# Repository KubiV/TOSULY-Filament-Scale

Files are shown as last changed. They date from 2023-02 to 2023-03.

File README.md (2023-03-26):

# TOSULY ALFA (V0.1)
## _DIY Filament scale integrated into filament holder_

Do It Yourself Filament Spool Scale which is integrated into the filament holder so you can easily monitor your remaining filament. By default it is not using batteries so you can hook it up straight to the printer/power suply. Optionaly you can add battery by soldering extension wires to prepared pads and than attach battery. 

## Features

- Open-source
- Custom PCB
- OLED 0.96 inch display
- Buttons (one under the display so it clicks when you push the display)
- By double-clicking button subtract spool dry mass
- Powered by Arduino Nano
- Compatible with stock Ender 3 spool holder, Prusa Original frame

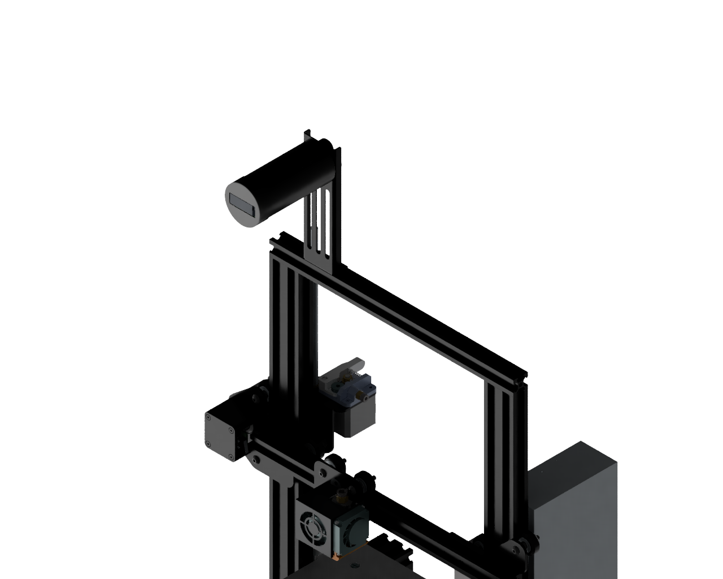
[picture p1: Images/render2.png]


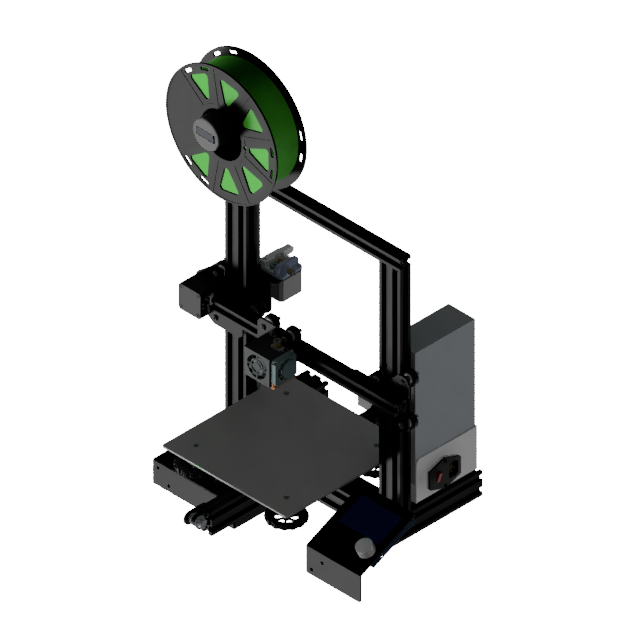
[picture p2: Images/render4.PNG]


## Needed

- 4x M3 screws (15mm for mounting PCBs)
- 2x M3 nuts (rectangle PCB mounting)
- 4x M4 screws (approx. 10 mm, and 2 with flat head)
- Custom PCB
- 7x1 horizontal pin header 2.54 mm pitch
- Arduino Nano
- USB cable (according on Arduino Nano variant)
- A DC-DC step-down converter and USB port for connecting the USB cable
- Load Cell 5 kg
- HX711 AD Module Weight Sensor
- 0.96 Inch OLED Module I2C
- 3x buttons 6 mm
- 3 resistor axial
- 3D printed parts (Upper, Body, Nut, Cover)

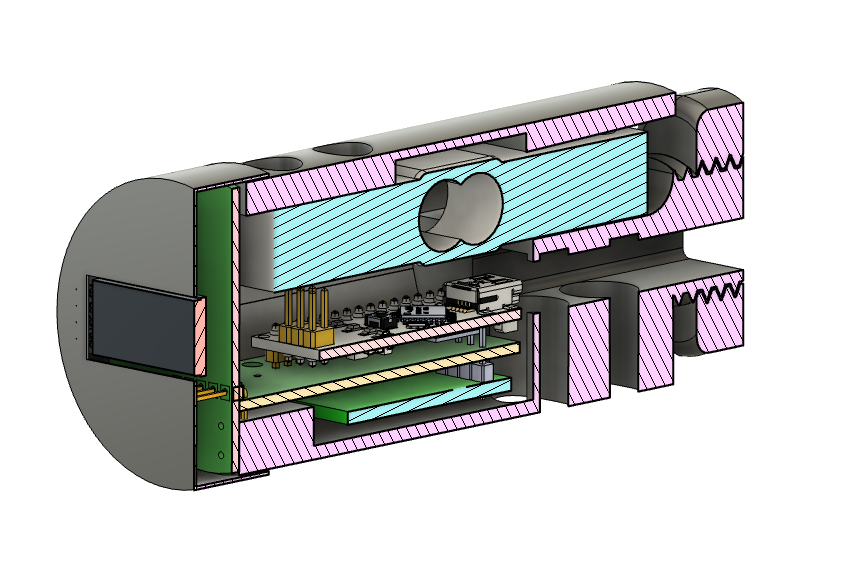
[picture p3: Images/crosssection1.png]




## Load cell

Compatible with both load cell designs - 12.7 x 12.7 x 75mm (type 1) or 12.7 x 12.7 x 80mm (type 2), holes for M4 bolts and two holes for M5 holes (type 2).

## 3D Printable parts

Mounting screw has 24 mm i diameter with according thread.

V02 design inspired by https://youtu.be/WO-hR7okl3k

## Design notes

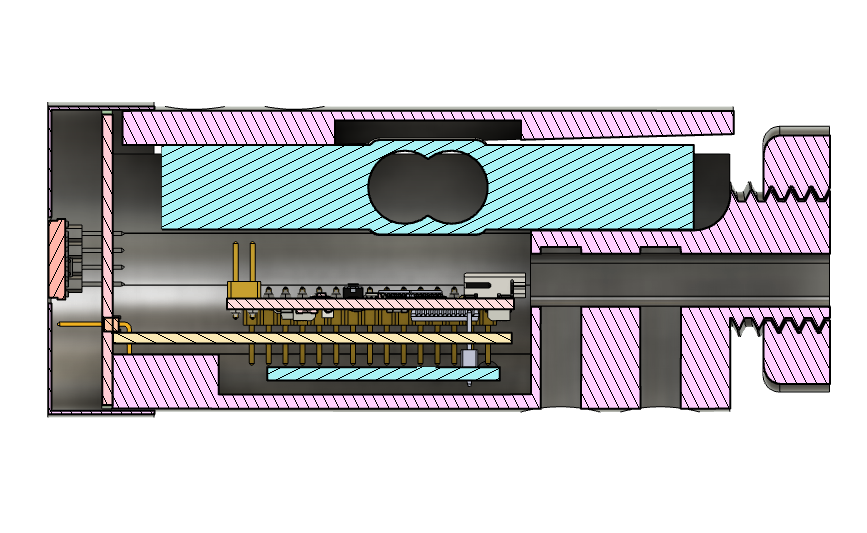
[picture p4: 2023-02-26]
Images/crosssection2.png

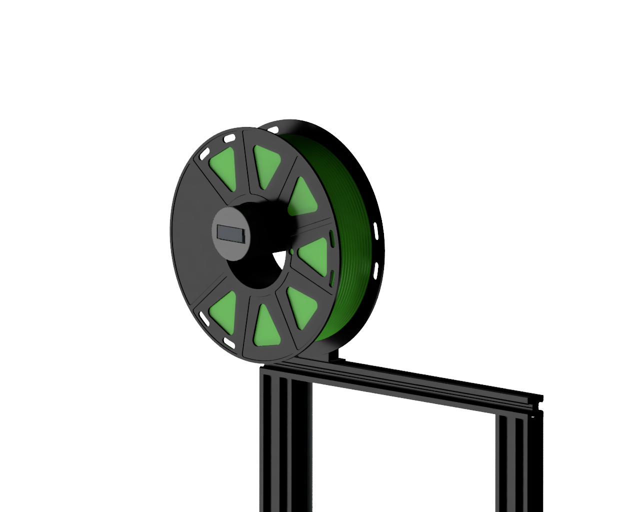
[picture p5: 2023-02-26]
Images/render3.PNG

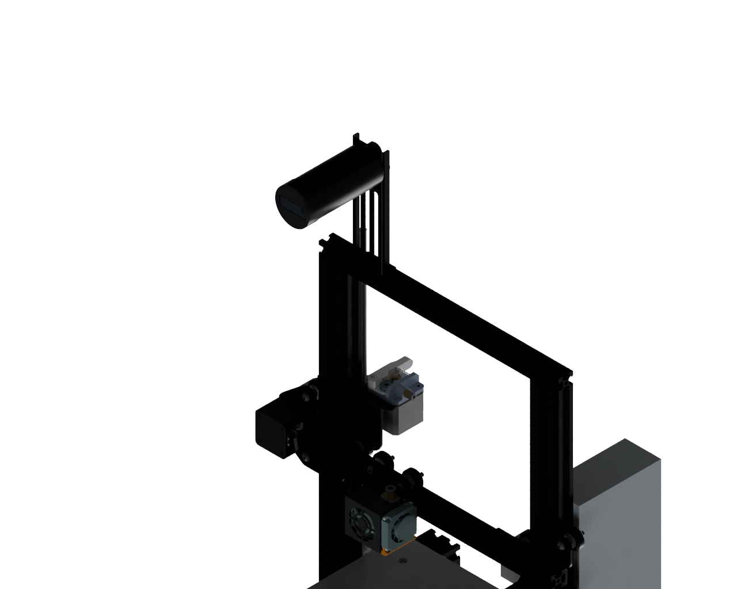
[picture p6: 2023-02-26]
Images/render1.png

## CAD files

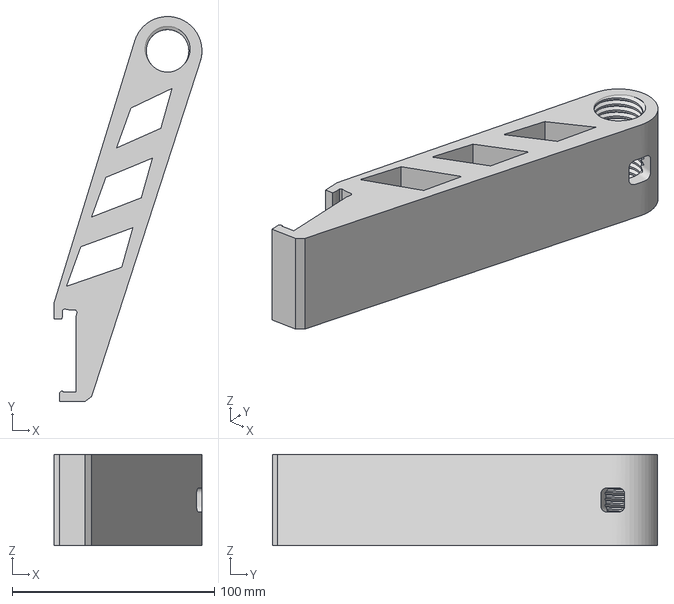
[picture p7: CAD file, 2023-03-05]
Hardware/CAD/OriginalPrusaAdaptor.3mf
73.1 x 190.3 x 45.0 mm

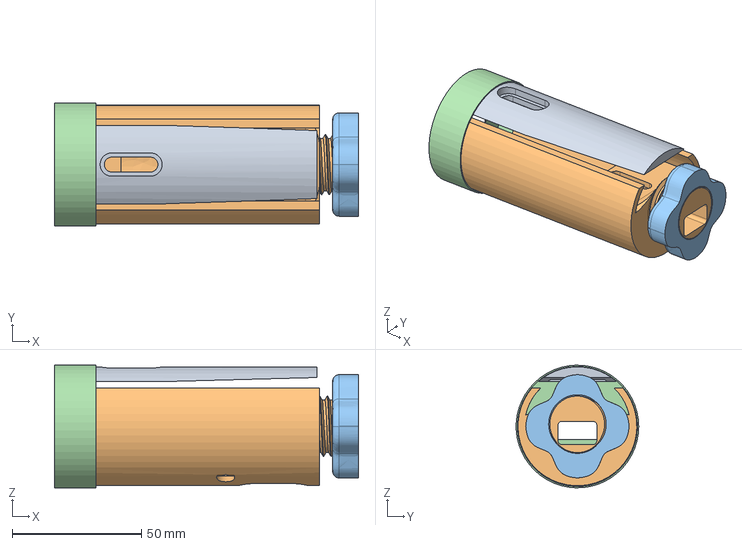
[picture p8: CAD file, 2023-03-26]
Hardware/CAD/V02/FilamentSpoolScale.step
117.7 x 47.5 x 47.5 mm

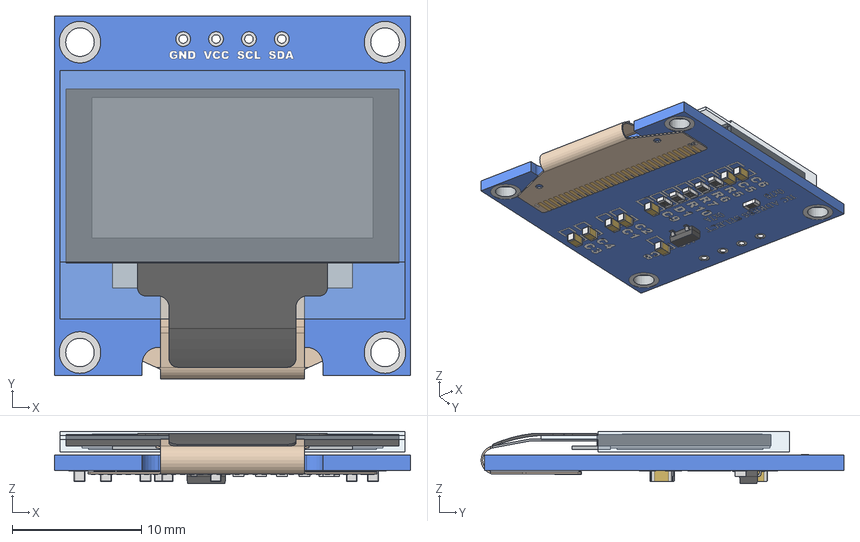
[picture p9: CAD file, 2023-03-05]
Resources/3D/0.96 OLED Module - i2C.stp
27.5 x 28.0 x 4.03 mm
0.96 OLED - Board - i2c
0.96 OLED - Glass
0.96 OLED - Flat Reverse
0603 Resistor x 6
SOT-23
0603 Capacitor x 8

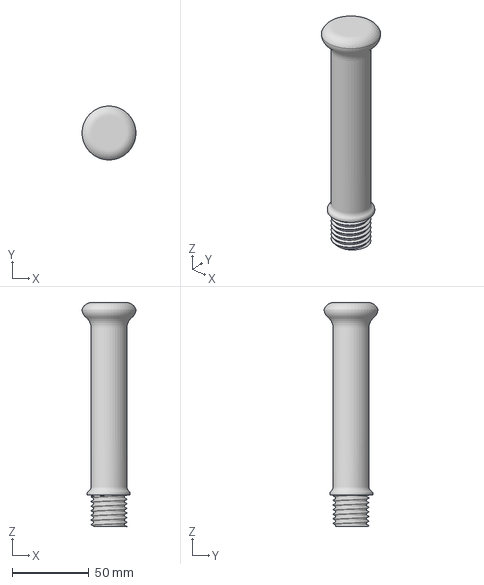
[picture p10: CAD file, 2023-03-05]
Hardware/CAD/NormalSpoolHolder.3mf
35.0 x 34.9 x 145.5 mm

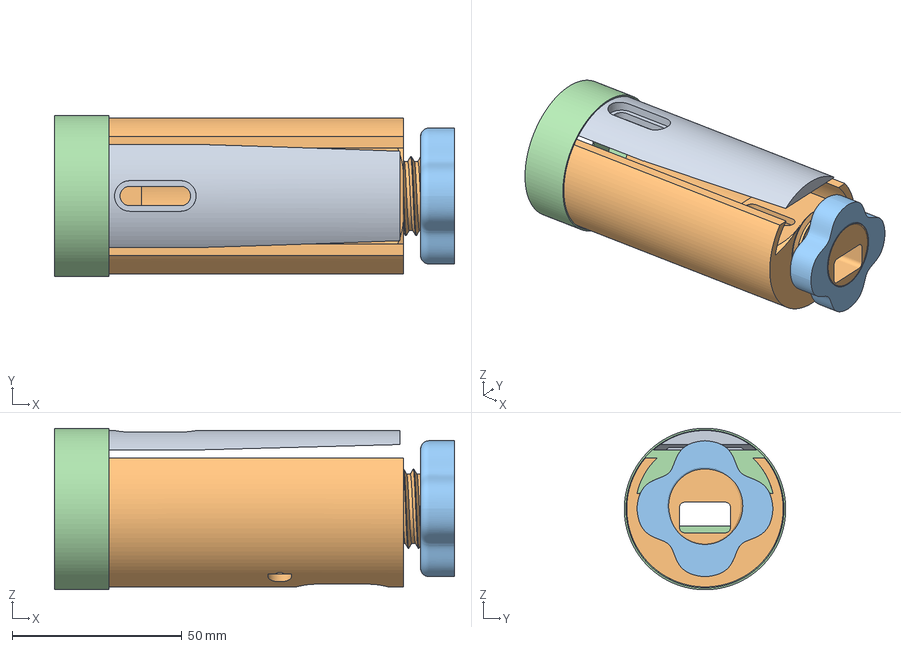
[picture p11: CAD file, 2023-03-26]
Hardware/CAD/V02/3Dprint_FilamentSpoolScaleV02.3mf
117.7 x 47.5 x 47.5 mm

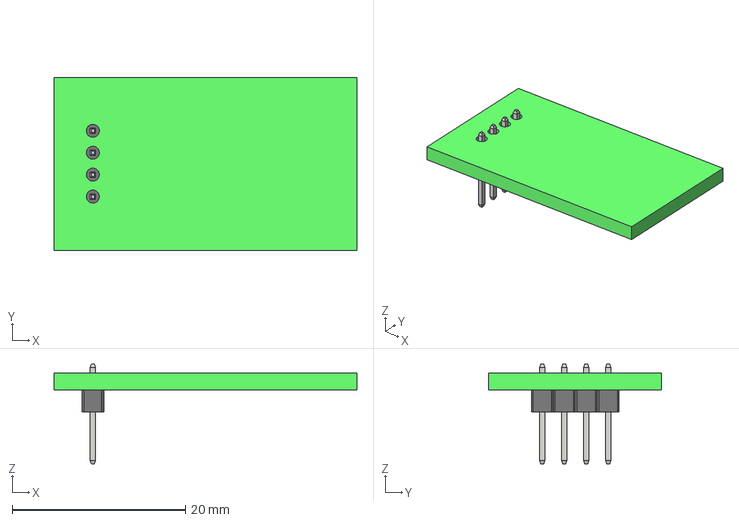
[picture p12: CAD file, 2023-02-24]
Resources/3D/XH711.step
35.0 x 20.0 x 11.5 mm
1x1_Pin_Header_2.54mm x 4

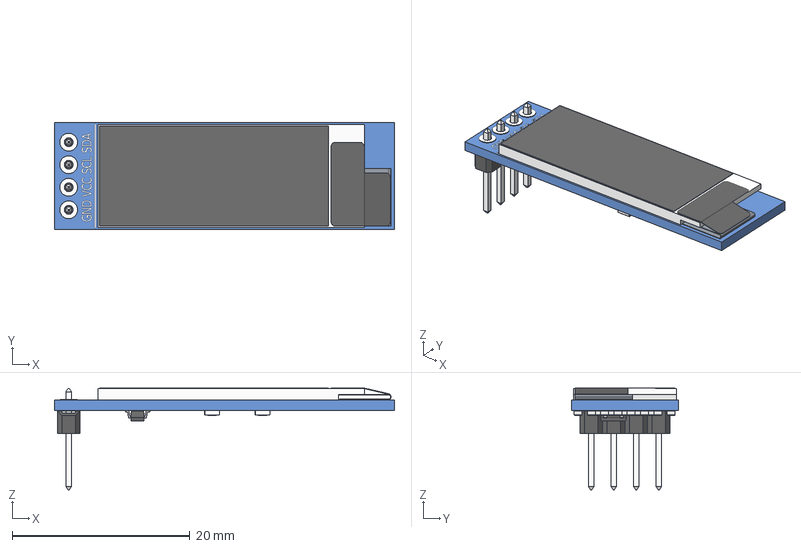
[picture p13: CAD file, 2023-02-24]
Resources/3D/OLED_0.91_128x32.stp
38.3 x 12.1 x 11.5 mm
OLED_0.91_128x32
Pin Header 4 x 1 TH 2.54mm Pitch
RESC-0603 x 13
2SD0601A

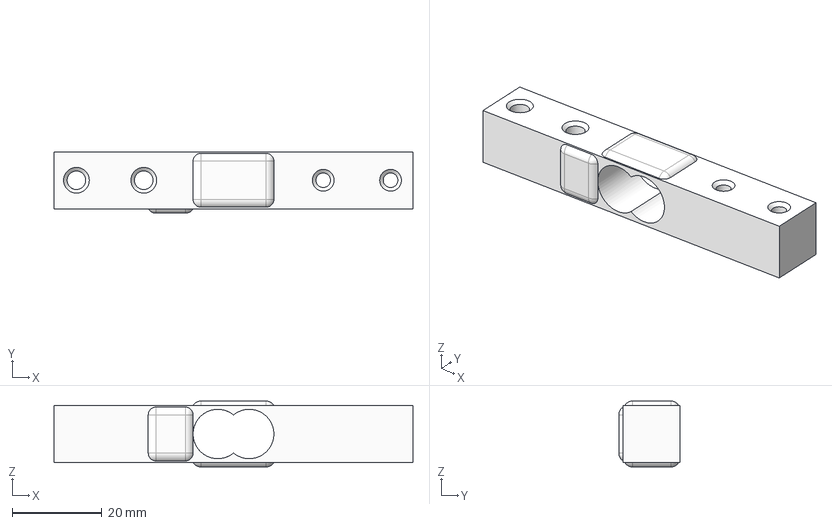
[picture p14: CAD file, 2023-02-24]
Resources/3D/loadCell.stp
80.0 x 13.7 x 14.7 mm

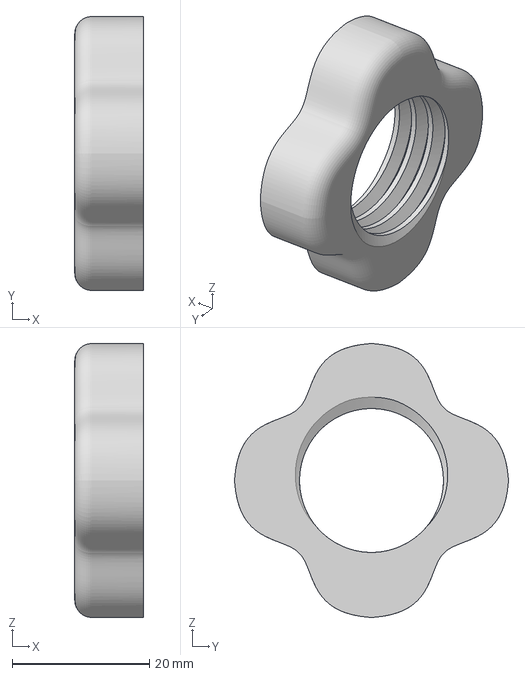
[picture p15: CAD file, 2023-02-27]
Hardware/CAD/Nut.3mf
10.0 x 40.0 x 40.0 mm

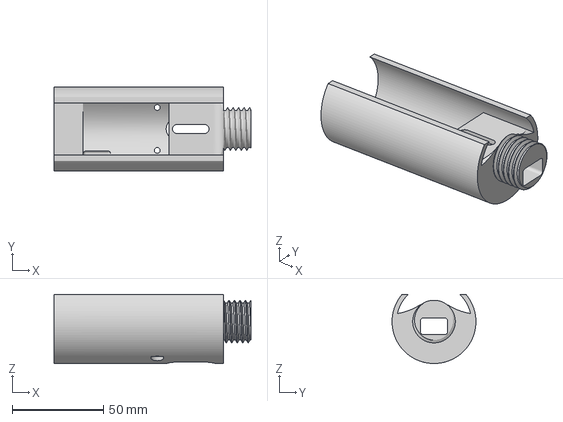
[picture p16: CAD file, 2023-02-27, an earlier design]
Hardware/CAD/V01/Individual parts/body.3mf
108.0 x 46.0 x 37.9 mm

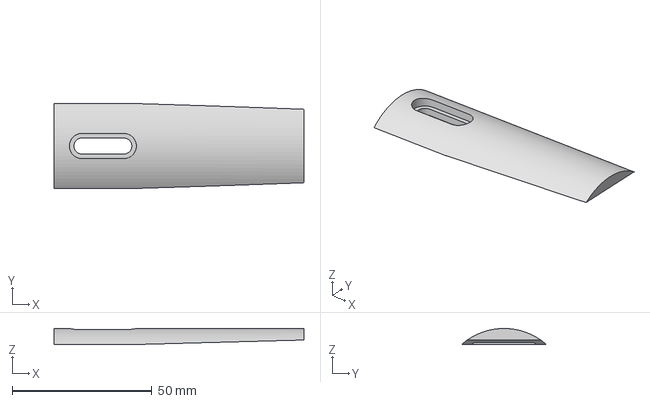
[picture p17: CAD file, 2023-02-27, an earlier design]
Hardware/CAD/V01/Individual parts/upper.3mf
89.5 x 30.4 x 5.74 mm

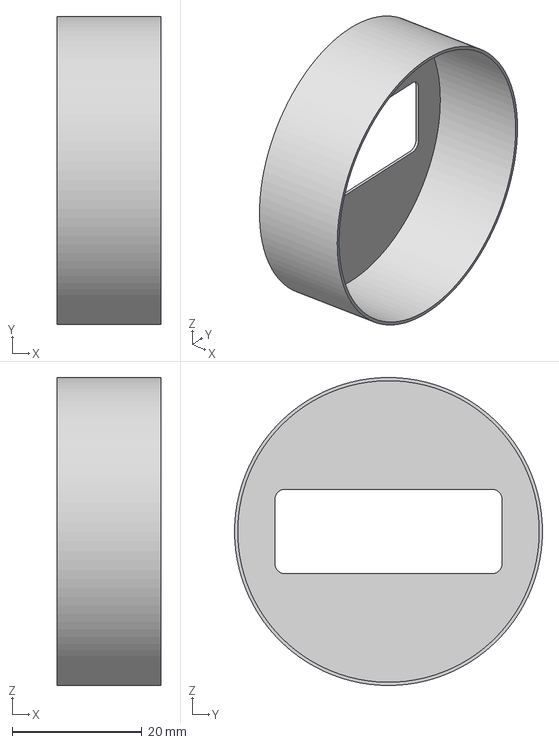
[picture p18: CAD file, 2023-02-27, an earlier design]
Hardware/CAD/V01/Individual parts/cover.3mf
16.0 x 47.5 x 47.5 mm

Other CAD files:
Hardware/CAD/V01/3Dprint_FilamentSpoolScaleV01.3mf

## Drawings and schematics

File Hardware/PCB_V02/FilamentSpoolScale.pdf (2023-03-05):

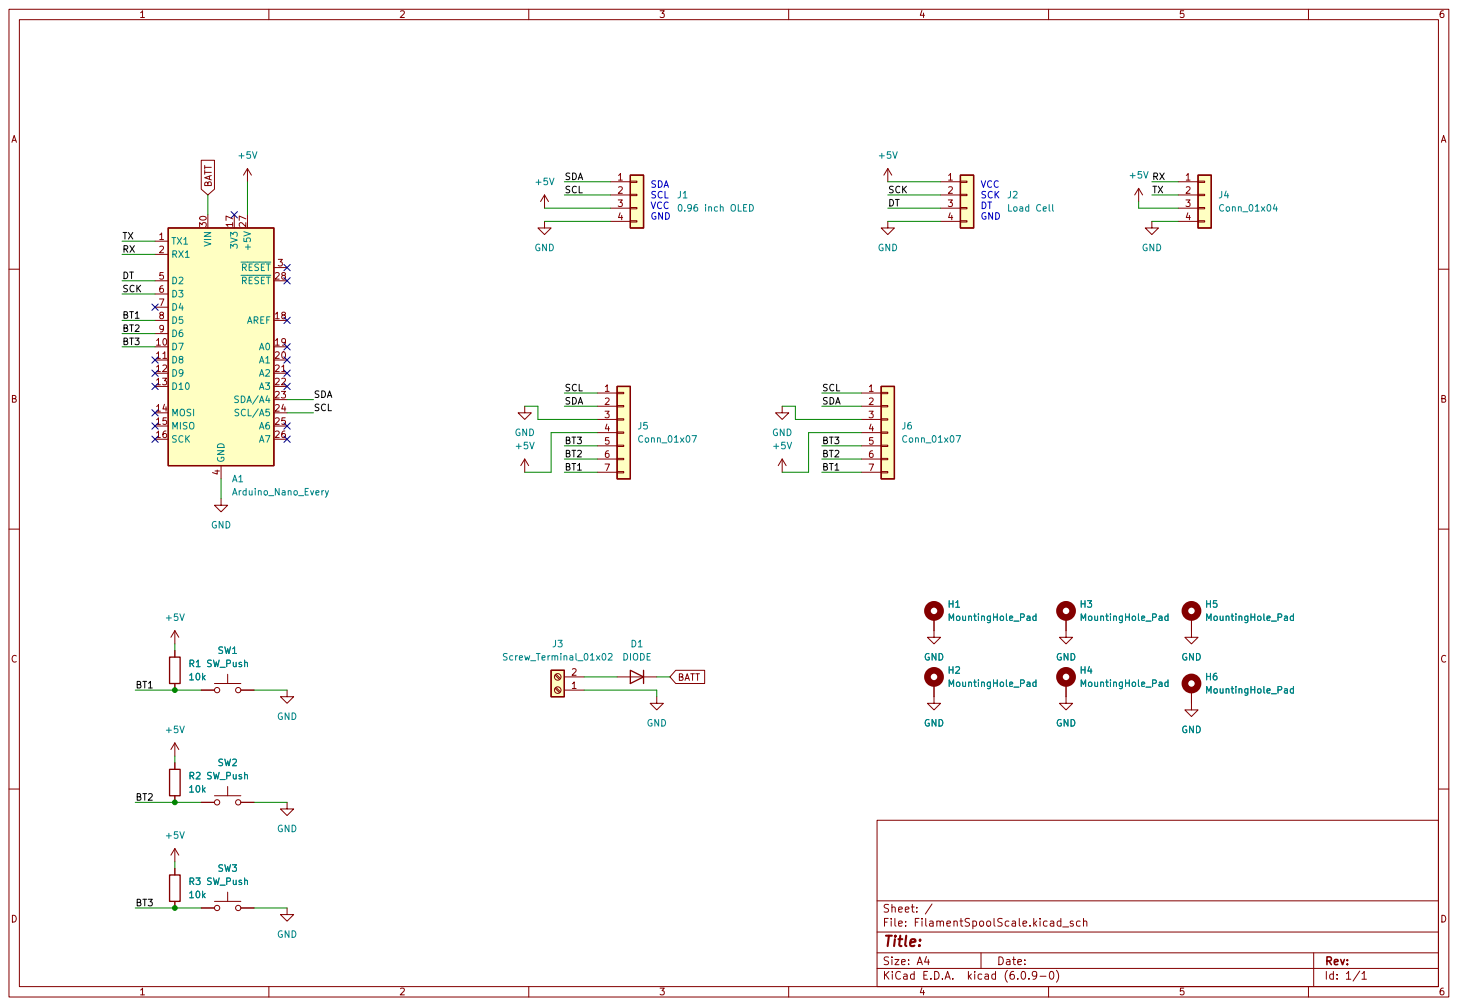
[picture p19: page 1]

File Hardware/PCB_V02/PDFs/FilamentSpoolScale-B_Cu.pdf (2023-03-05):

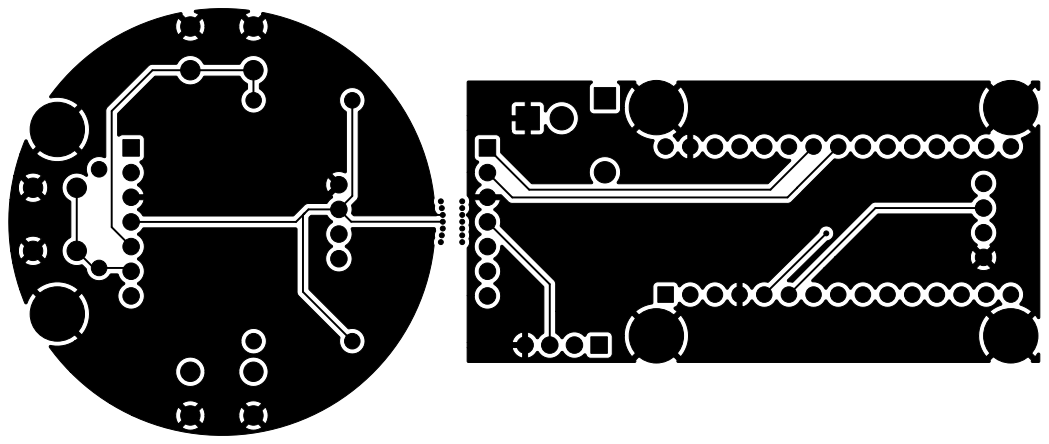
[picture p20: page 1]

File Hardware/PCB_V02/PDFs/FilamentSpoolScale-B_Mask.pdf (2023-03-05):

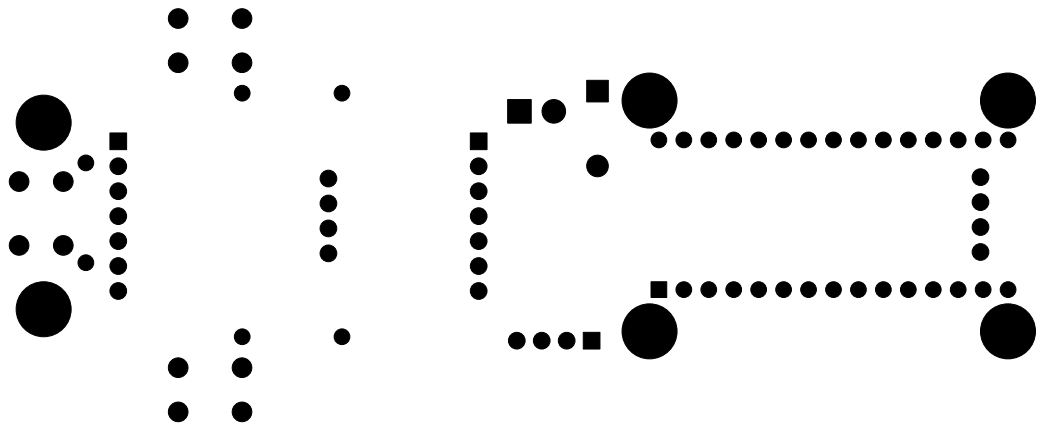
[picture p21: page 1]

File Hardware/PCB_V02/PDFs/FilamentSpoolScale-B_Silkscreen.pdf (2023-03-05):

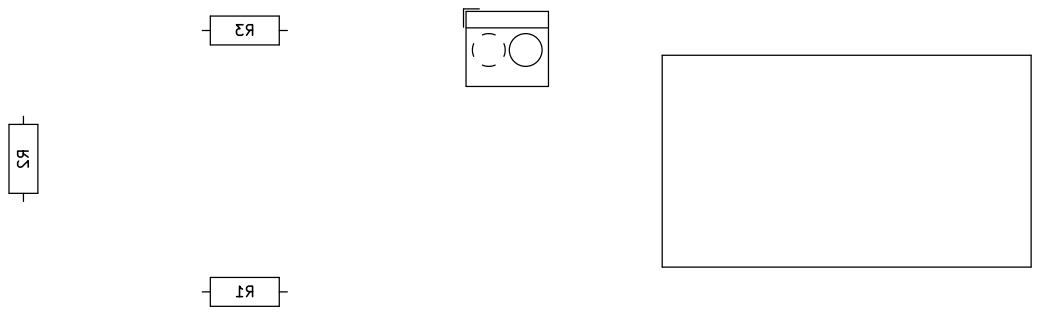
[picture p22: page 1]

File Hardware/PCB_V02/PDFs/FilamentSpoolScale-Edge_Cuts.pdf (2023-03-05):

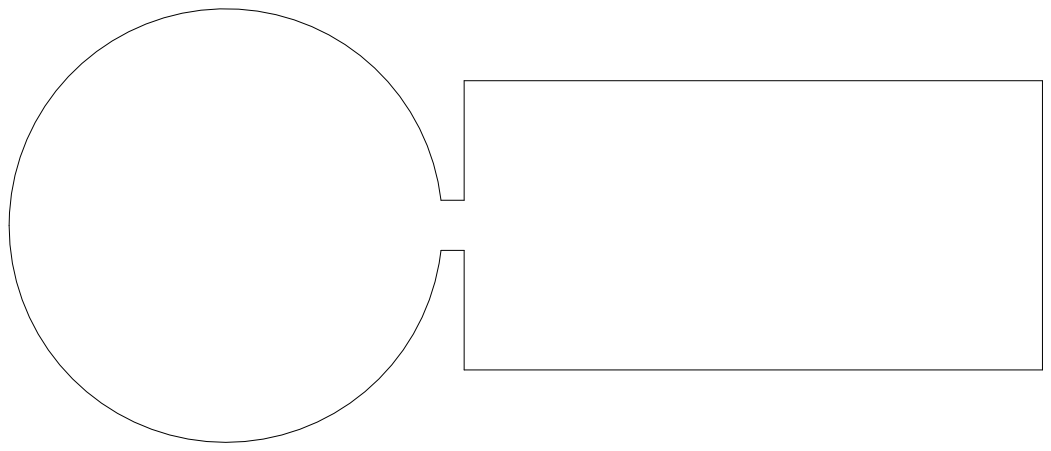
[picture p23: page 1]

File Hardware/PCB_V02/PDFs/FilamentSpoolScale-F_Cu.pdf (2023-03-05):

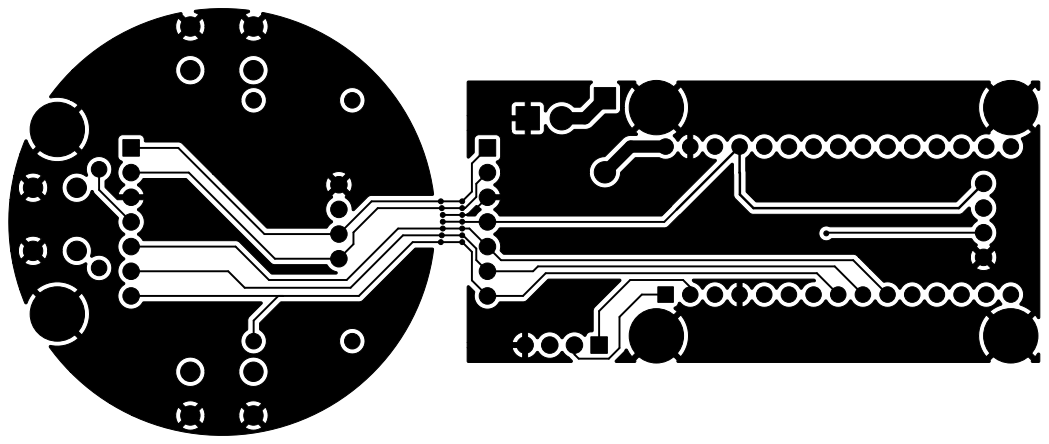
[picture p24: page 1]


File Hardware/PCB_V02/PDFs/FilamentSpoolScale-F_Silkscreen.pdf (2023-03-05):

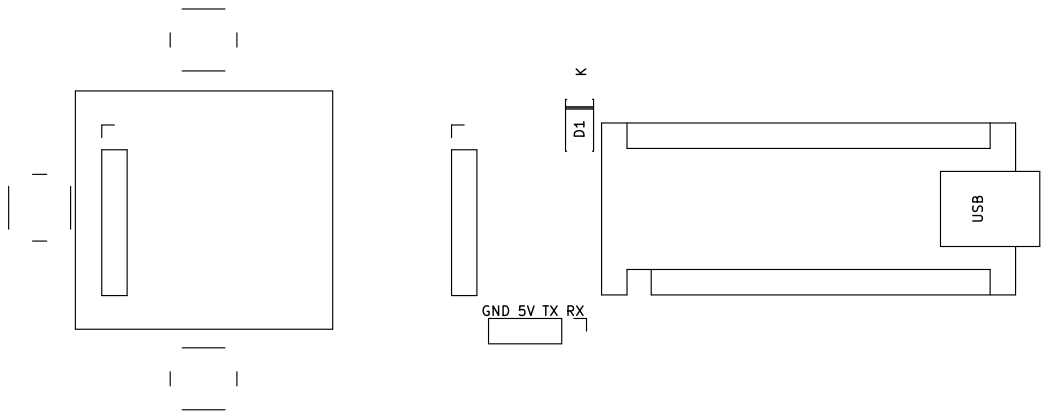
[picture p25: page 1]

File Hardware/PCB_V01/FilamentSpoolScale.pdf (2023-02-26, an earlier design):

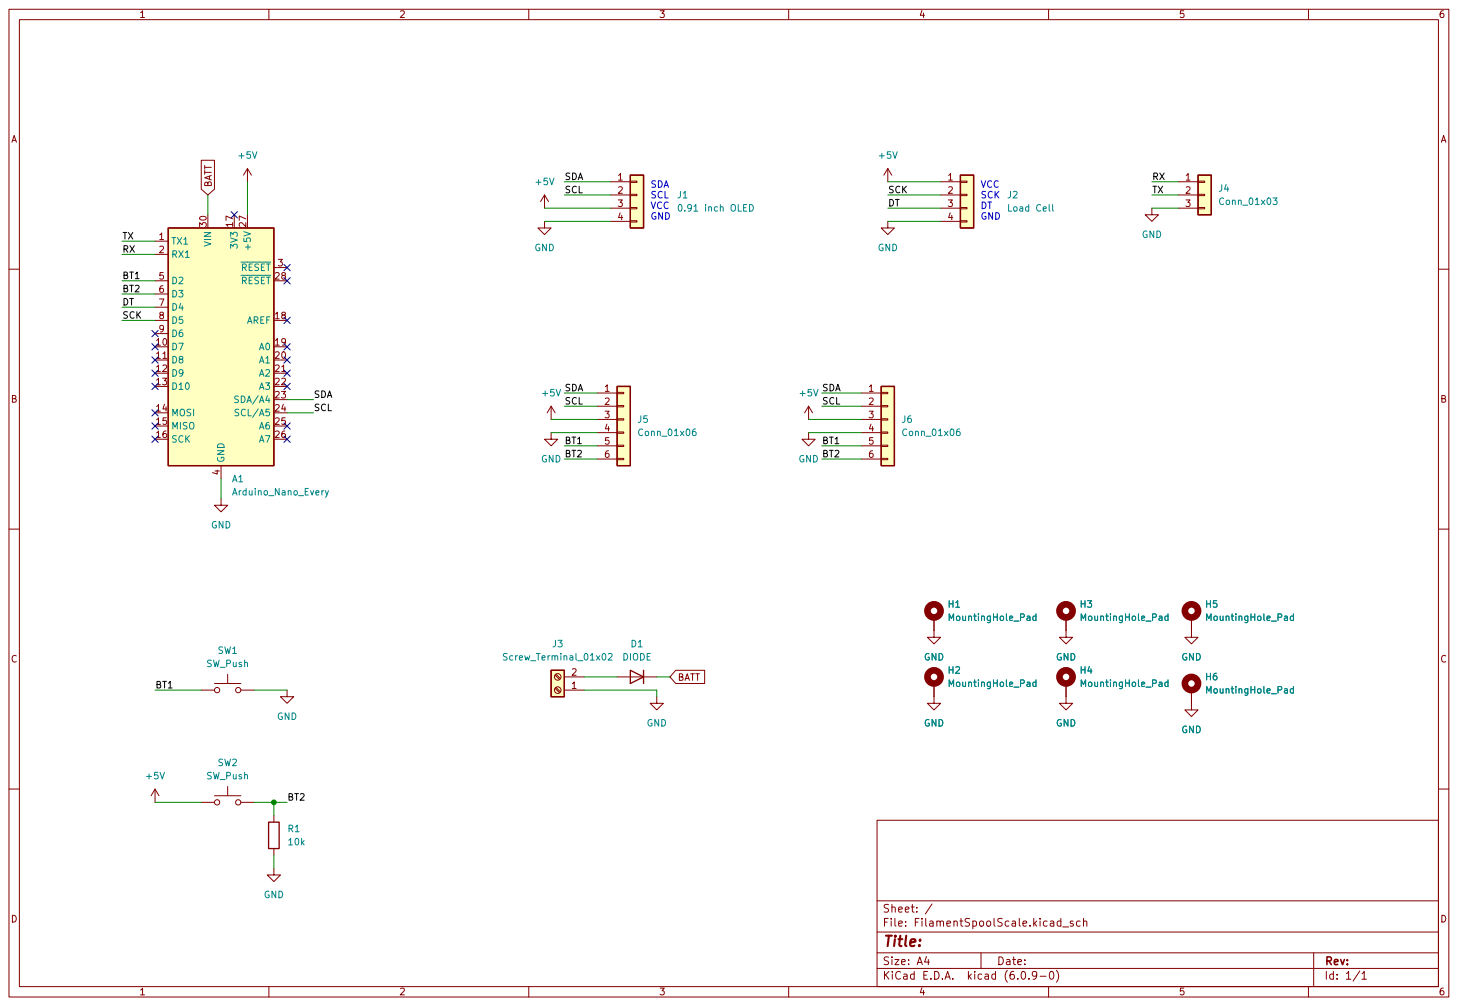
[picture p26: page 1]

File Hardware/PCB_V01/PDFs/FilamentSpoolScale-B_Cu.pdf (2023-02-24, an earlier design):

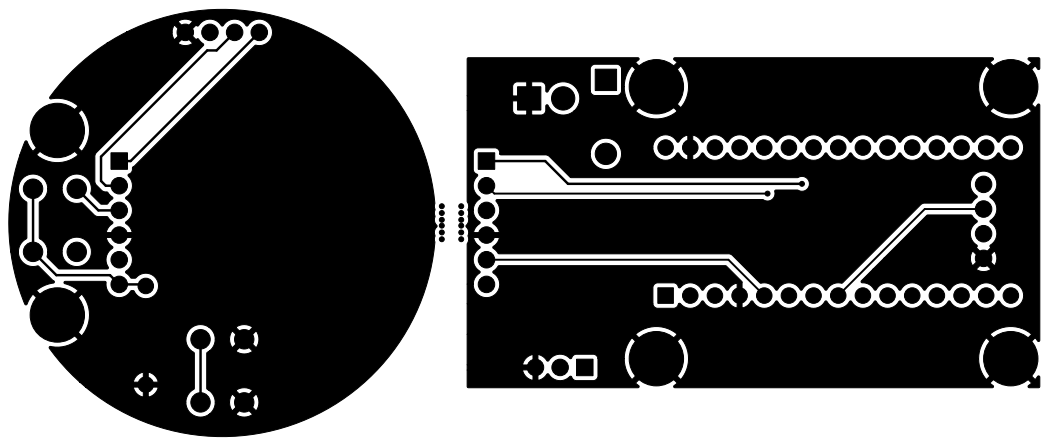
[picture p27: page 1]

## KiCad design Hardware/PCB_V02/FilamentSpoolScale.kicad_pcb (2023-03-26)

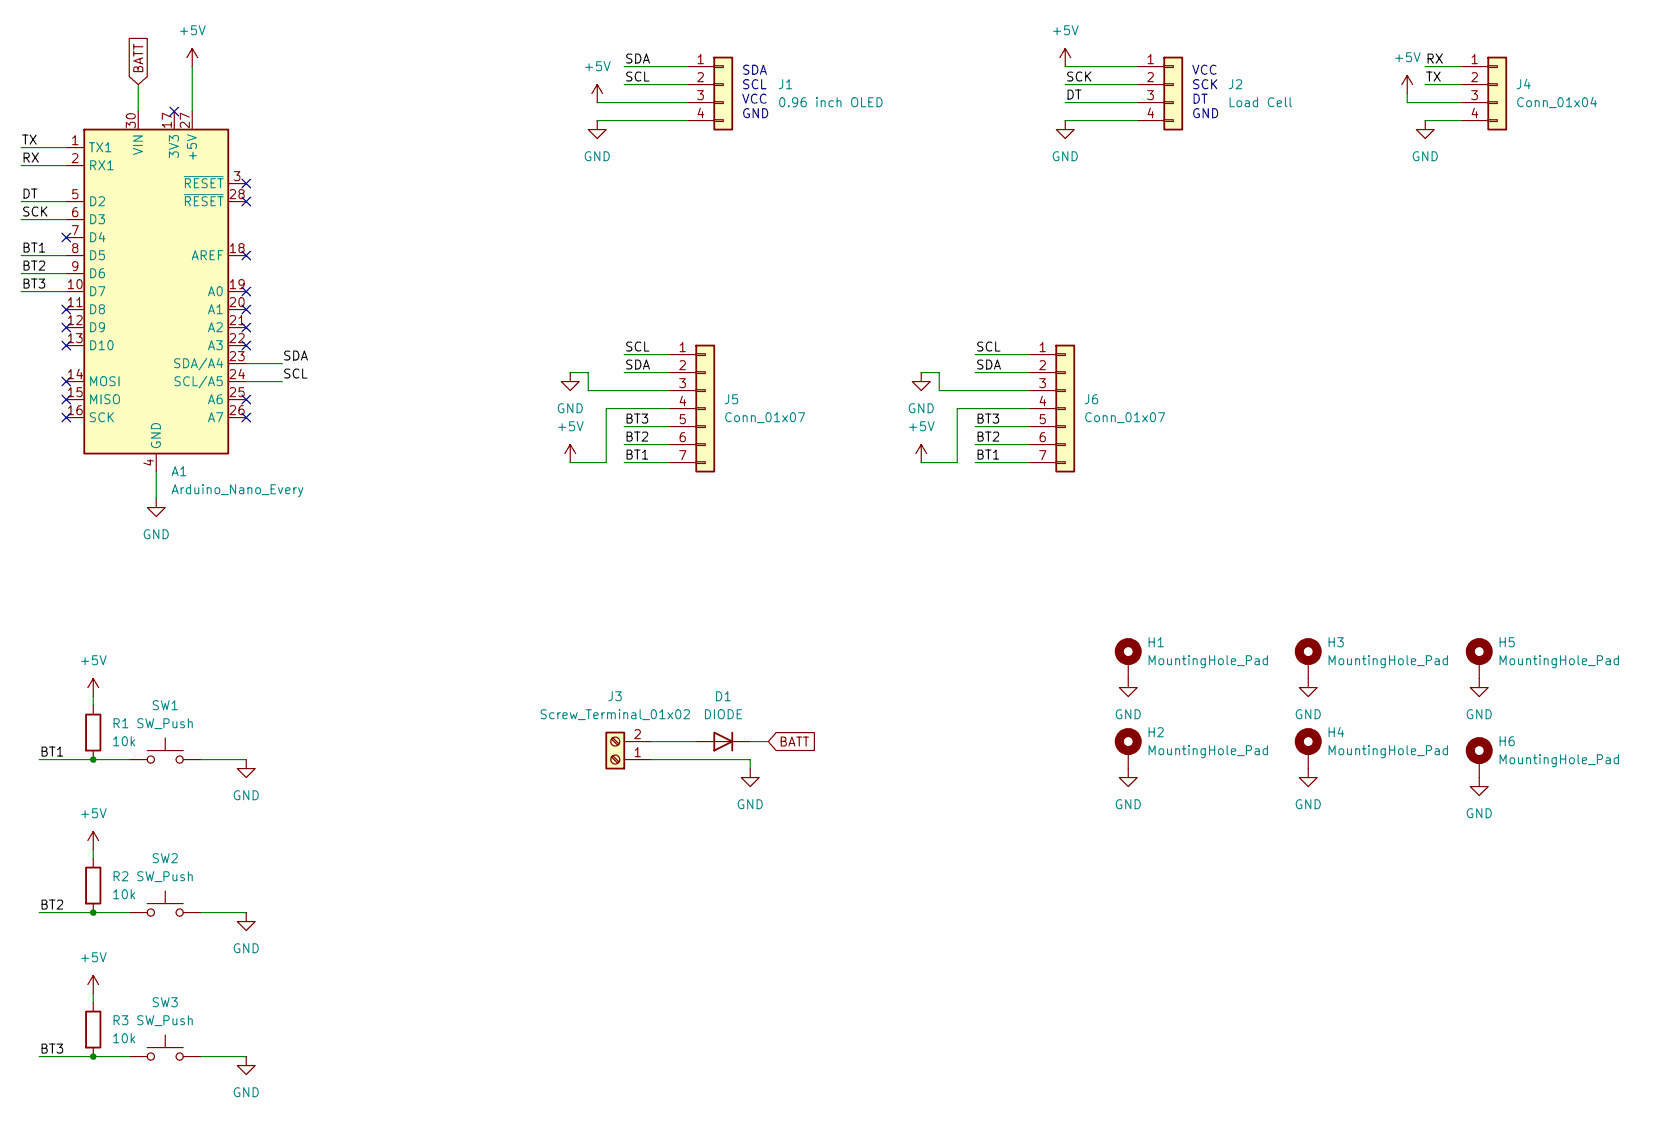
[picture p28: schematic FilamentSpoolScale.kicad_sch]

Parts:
A1: Arduino_Nano_Every; Arduino_Nano
D1: DIODE; D_DO-41_SOD81_P7.62mm_Horizontal
H1, H2, H3, H4, H5, H6: MountingHole_Pad; MountingHole_3.2mm_M3_DIN965_Pad_TopBottom
J1: 0.96 inch OLED; 0.96 inch OLED I2C
J2: Load Cell; LoadCellAmplifier
J3: Screw_Terminal_01x02; TerminalBlock_4Ucon_1x02_P3.50mm_Horizontal
J4: Conn_01x04; PinHeader_1x04_P2.54mm_Vertical
J5, J6: Conn_01x07; PinHeader_1x07_P2.54mm_Vertical
R1, R2, R3: 10k; R_Axial_DIN0207_L6.3mm_D2.5mm_P10.16mm_Horizontal
SW1, SW2, SW3: SW_Push; SW_PUSH_6mm_H4.3mm

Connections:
+5V: A1.27 (+5V), J1.3, J2.1, J4.3, J5.4, J6.4, R1.1, R2.1, R3.1
/BT1: A1.8 (D5), J5.7, J6.7, R1.2, SW1.1
/BT2: A1.9 (D6), J5.6, J6.6, R2.2, SW2.1
/BT3: A1.10 (D7), J5.5, J6.5, R3.2, SW3.1
/DT: A1.5 (D2), J2.3
/RX: A1.2 (RX1), J4.1
/SCK: A1.6 (D3), J2.2
/SCL: A1.24 (SCL/A5), J1.2, J5.1, J6.1
/SDA: A1.23 (SDA/A4), J1.1, J5.2, J6.2
/TX: A1.1 (TX1), J4.2
BATT: A1.30 (VIN), D1.2 (K)
GND: A1.4 (GND), A1.29 (GND), H1.1, H2.1, H3.1, H4.1, H5.1, H6.1, J1.4, J2.4, J3.1, J4.4, J5.3, J6.3, SW1.2, SW2.2, SW3.2
unnamed: D1.1 (A), J3.2

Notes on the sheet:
SDA SCL VCC GND
VCC SCK DT GND

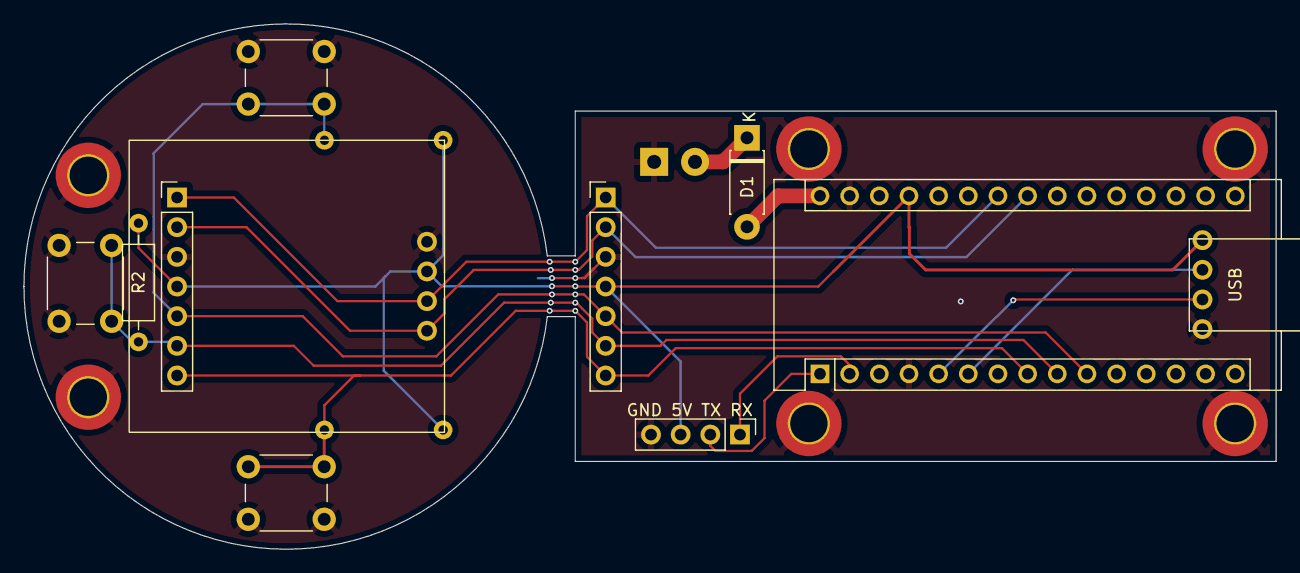
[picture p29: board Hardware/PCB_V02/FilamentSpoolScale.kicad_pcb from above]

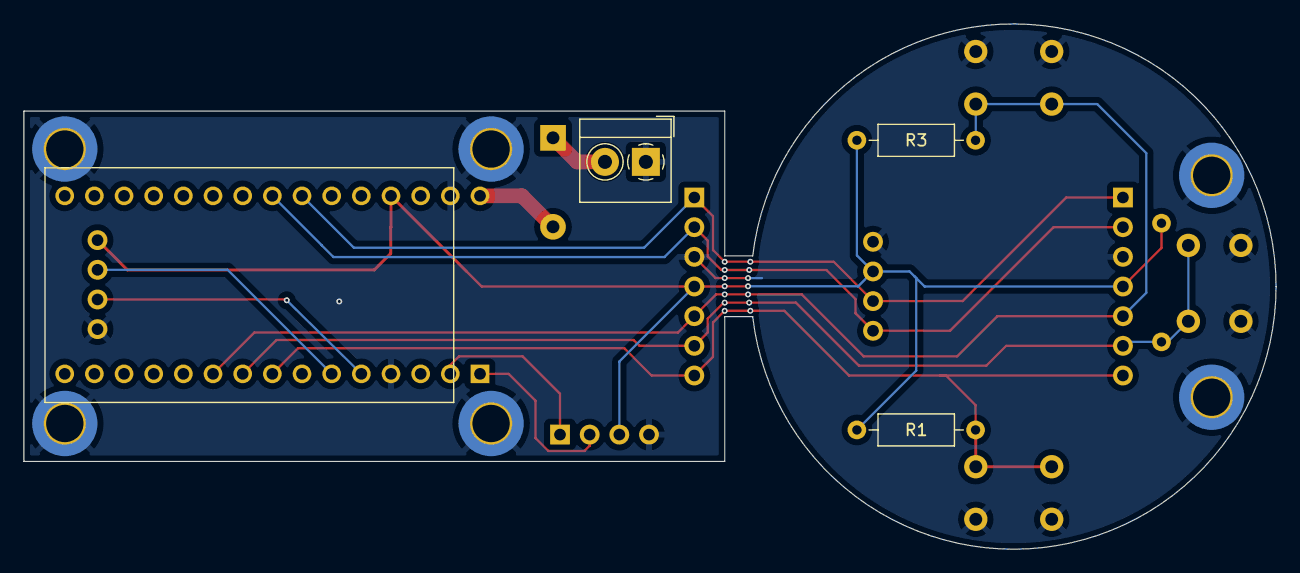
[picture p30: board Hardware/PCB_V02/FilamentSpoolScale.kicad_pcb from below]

Board: 2 copper layers, 107.2 x 45.0 mm, 20 parts (4 on the bottom side), 13 nets.

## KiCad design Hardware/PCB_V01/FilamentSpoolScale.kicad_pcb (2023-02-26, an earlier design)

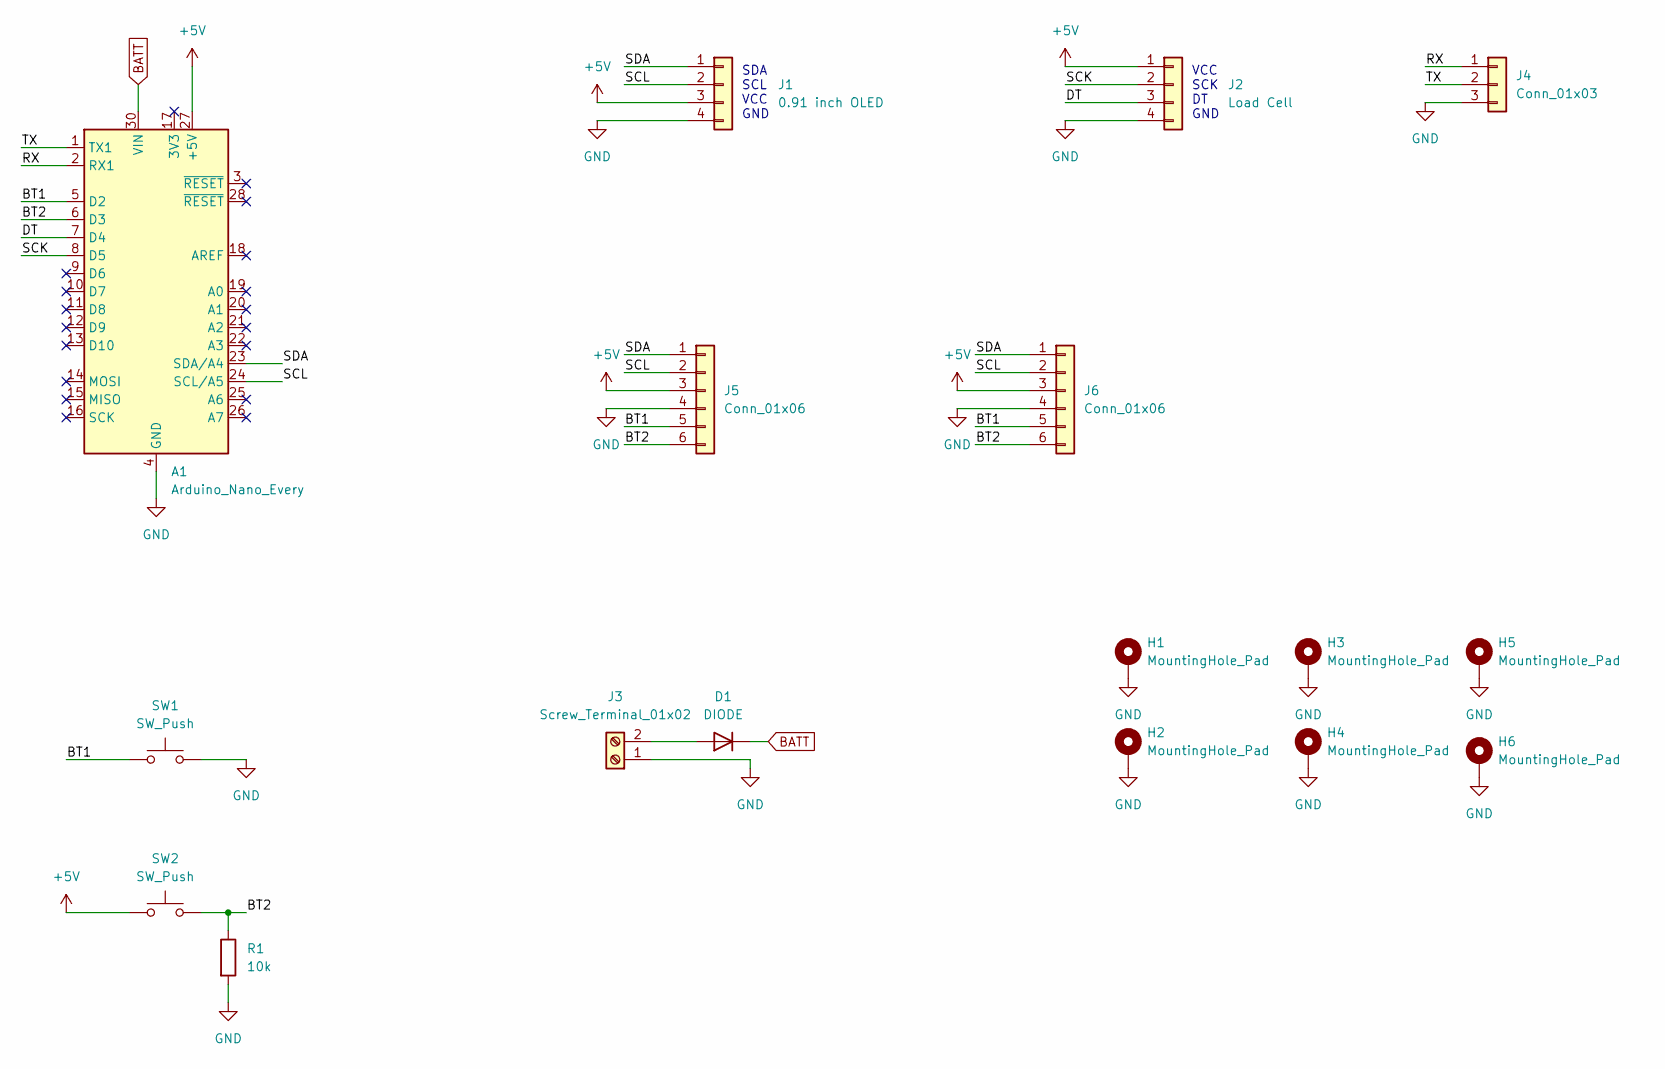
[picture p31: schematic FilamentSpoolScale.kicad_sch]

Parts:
A1: Arduino_Nano_Every; Arduino_Nano
D1: DIODE; D_DO-41_SOD81_P7.62mm_Horizontal
H1, H2, H3, H4, H5, H6: MountingHole_Pad; MountingHole_3.2mm_M3_DIN965_Pad_TopBottom
J1: 0.91 inch OLED; 0.91inch OLED
J2: Load Cell; LoadCellAmplifier
J3: Screw_Terminal_01x02; TerminalBlock_4Ucon_1x02_P3.50mm_Horizontal
J4: Conn_01x03; PinHeader_1x03_P2.54mm_Vertical
J5: Conn_01x06; PinHeader_1x06_P2.54mm_Vertical
J6: Conn_01x06; PinHeader_1x06_P2.54mm_Horizontal
R1: 10k; R_Axial_DIN0207_L6.3mm_D2.5mm_P10.16mm_Horizontal
SW1, SW2: SW_Push; SW_PUSH_6mm_H4.3mm

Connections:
+5V: A1.27 (+5V), J1.3, J2.1, J5.3, J6.3, SW2.1
/BT1: A1.5 (D2), J5.5, J6.5, SW1.1
/BT2: A1.6 (D3), J5.6, J6.6, R1.1, SW2.2
/DT: A1.7 (D4), J2.3
/RX: A1.2 (RX1), J4.1
/SCK: A1.8 (D5), J2.2
/SCL: A1.24 (SCL/A5), J1.2, J5.2, J6.2
/SDA: A1.23 (SDA/A4), J1.1, J5.1, J6.1
/TX: A1.1 (TX1), J4.2
BATT: A1.30 (VIN), D1.2 (K)
GND: A1.4 (GND), A1.29 (GND), H1.1, H2.1, H3.1, H4.1, H5.1, H6.1, J1.4, J2.4, J3.1, J4.3, J5.4, J6.4, R1.2, SW1.2
unnamed: D1.1 (A), J3.2

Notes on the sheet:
SDA SCL VCC GND
VCC SCK DT GND

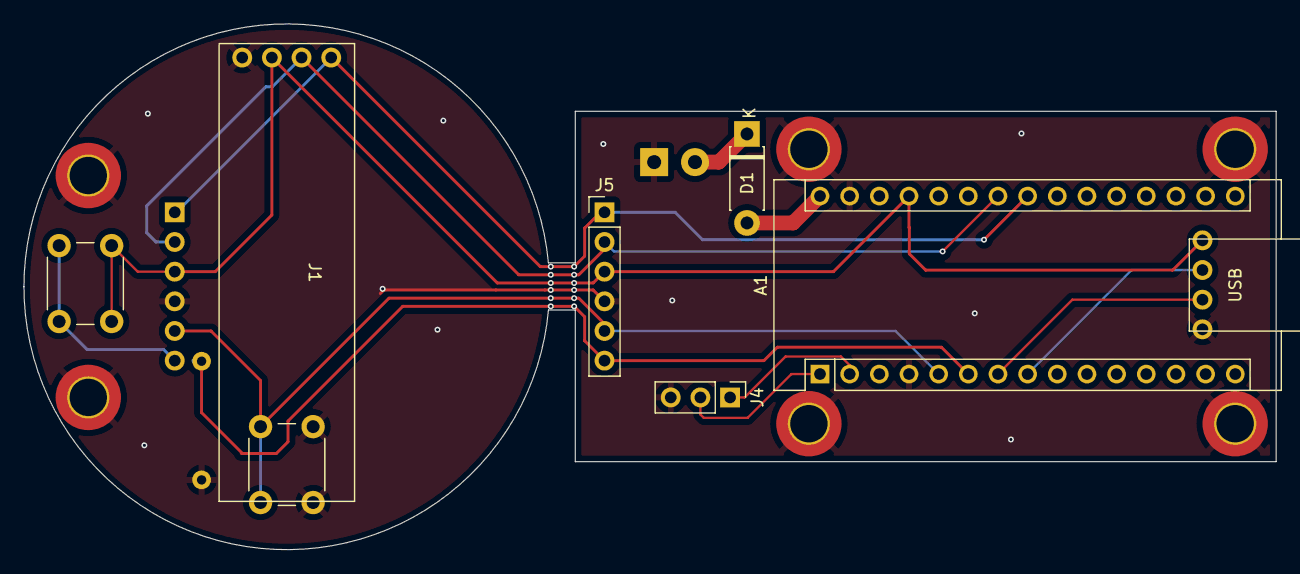
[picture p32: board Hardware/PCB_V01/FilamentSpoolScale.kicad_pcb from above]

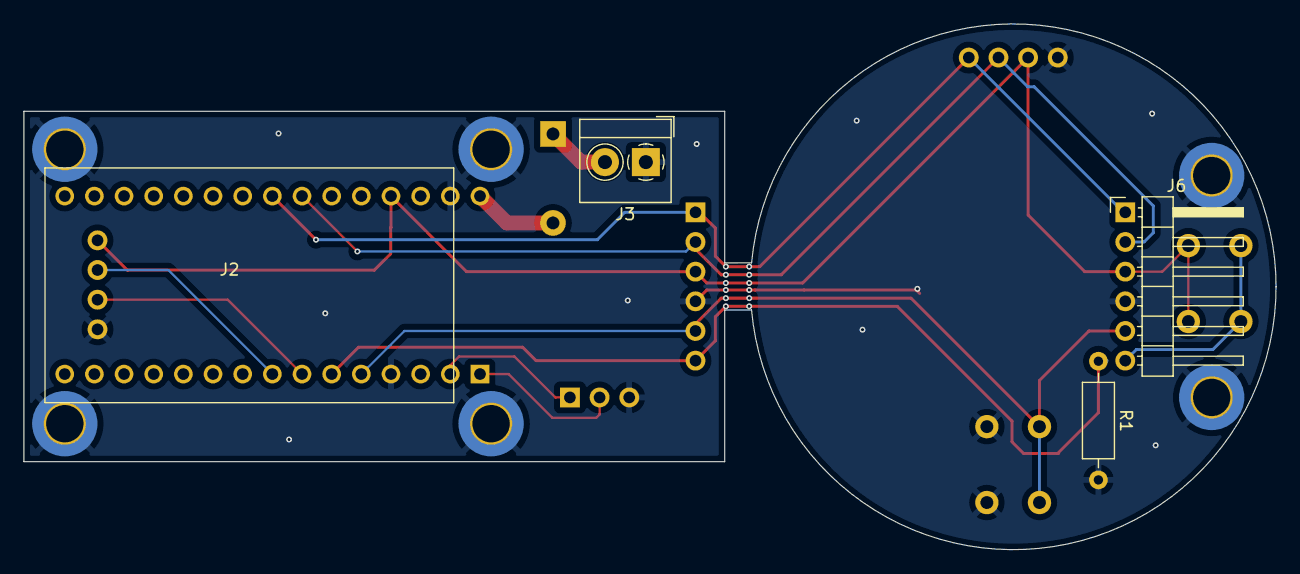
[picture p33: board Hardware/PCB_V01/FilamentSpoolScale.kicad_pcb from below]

Board: 2 copper layers, 107.2 x 45.0 mm, 17 parts (4 on the bottom side), 12 nets.

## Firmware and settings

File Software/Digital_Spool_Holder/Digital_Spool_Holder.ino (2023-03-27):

//SOURCE: https://www.instructables.com/Digital-Spool-Holder-with-Scale/

/*
Digital Spool Holder

This sketch is for a scale made to measure the weight (g) of the
remaining material in a spool. It was made mainly for 3D printers but it can be
used for any kind of spool or container.

The main difference between this and a common scale is that this device has the
possibility to add multiple profiles to store different Tare values
so that way we can measure only the weight of the remaining filament excluding
the weight of the empty spool, because each brand of filaments has a different
weight and material for the spool itself.

It uses a load cell connected to a HX711 module.

We also use an 1.3" OLED display 128x64 I2C with SSD1306 driver using the
U8GLIB library. It also works on a 0.96" OLD display of the same characteristics
but everything would look smaller so I don't recommend it.


Features:
 * This sketch can measure weights from 10g to 9999g.
 * There are 3 buttons (LEFT, ENTER, RIGHT) that can be used for scrolling 
   through different profiles and navigate through the menu system.
 * You can add, edit and delete profiles using the menu system.
   It can store up to 20 profiles, with their own name and Tare value.
   Maximum 21 characters for the name of each profile.
 * You can do a full calibration for the load cell using the menu system, 
   so there's no need to edit this sketch in any way.
 * Configurable deadzone with real-time reading on the display. The deadzone
   helps ignoring the fluctuations of the constant pulling/pushing of the
   filament in the 3D printer.
 * All the settings are stored in the EEPROM so it's going to remember all the 
   settings after powering the device off.
 * There is an option in the menu to FACTORY RESET arduino for clearing the EEPROM (user data).
 * Auto-center the tittle text in the main/normal screen ignoring spaces to the right.
 * When adding a new profile, it's going to save the new profile after the current 
   profile so the order can be arranged in a predictable way. To make this work it
   required a lot of effort so even though you might take this for granted, it's not
   a trivial feature.
 * In the menu you can set the amount of deadzone to ignore the peaks when the 3D printer 
   pulls the filament, so we show the most realistic estimate of the actual weight left in the spool.
 * When powering ON, changing profiles or returning from the menu, it shows the weight 
   starting at the lower edge of the deadzone so the device is ready to measure the decrease of weight
   of the filament immediately.
 * No timeout for being on the menu. Yes, that's right, this is a feature. Why? I hate timeouts
   that will exit the menu if no operation is done after a few seconds, but I think that is
   a bad design that causes stress and frustration because you feel like you need to rush things
   with the threat of having to start all over from the beginning. You are not going to find anything
   like that in here.


More details about the project in here: https://www.instructables.com/Digital-Spool-Holder-with-Scale/

Pins for HX711 module to arduino:
 * GND         = GND
 * VCC         = 5V
 * DT (DATA)   = 2
 * SCK (CLOCK) = 3

Load cell connection to the HX711 module:
 * RED   = E+
 * BLACK = E-
 * WHITE = A-
 * GREEN = A+

To control everything we use 3 buttons:
 * LEFT ARROW  = Pin 5: Scroll to the left.
 * ENTER       = Pin 6: This button is to enter the menu and select options.
 * RIGHT ARROW = Pin 7: Scroll to the right.
Note: When you press the button, the pin should receive GROUND, and when you
release the button the pin should receive 5V. We use the internal pullup
resistor for this but I recommend adding an aditional 10K resistor to each pin
connected to each button pin and 5V. This way is going to be more reliable.
I say this because I've seen the internal pullup resistor fail after some time.

Pins for OLED Display:
 * GND = GND
 * VCC = 5V
 * SCL = A5
 * SDA = A4

It's a good idea to put a resistor (3.3K) between A4-5V and A5-5V to help stabilize
the connection. What that does is to pull-up the I2C pins to make it more reliable
and prevents lock-ups (yes, this can happen without adding resistors).


HX711 maximum raw value allowed: 8388607

Load cell actual maximum weight reached:
 * 2Kg = 8.4Kg


Reference of weight for empty spools:
 * Plastic = 244g
 * Cardboard = 177g


Note: When exposing the cell to very heavy weights, more than the rating,
the cell permanetly bends a little so may require Tare. Also, with time this
can happen but only very little (around 3g).


Ucglib library: https://github.com/olikraus/ucglib
HX711 library: https://github.com/bogde/HX711


User Reference Manual: https://github.com/olikraus/u8glib/wiki/userreference
List of fonts: https://github.com/olikraus/u8glib/wiki/fontsize

Sketch made by: InterlinkKnight
Last modification: 2022/12/18
*/





// Pins:
const byte LeftButtonPin = 7;  // Pin for LEFT button
const byte EnterButtonPin = 6;  // Pin for ENTER button
const byte RightButtonPin = 5;  // Pin for RIGHT button


#include "U8glib.h"  // Include U8glib library for the display

// Create display and set pins:
U8GLIB_SSD1306_128X64 u8g(U8G_I2C_OPT_NONE|U8G_I2C_OPT_DEV_0);  // Dev 0, Fast I2C / TWI


#include "HX711.h"  // Include HX711 library for the load cell

// Set pins for HX711 module:
const byte LOADCELL_DOUT_PIN = 2;
const byte LOADCELL_SCK_PIN = 3;

HX711 scale;  // Create object for the load cell and give it a name


#include "EEPROM.h"  // Include EEPROM library to be able to store settings





///////////////
// ADJUSTMENTS:
///////////////
// The following items are the values that you could want to change:

// Smoothing the weight:
const byte numReadings1 = 20;  // Number of samples for smoothing. The more samples, the smoother the value
                               // although that will delay refreshing the value. 

const byte MinimumWeightAllowed = 10;  // When the weight is below this value, we are going to consider that the weight is actually 0 so we show a 0


// Debouncing buttons:
const byte ButtonDebouncingAmount = 2;  // Debouncing amount (cycles) for how long to wait. The higher, the more
                                        // it will wait to see if button remain release to really consider is released.
                                        // It adds a lag to make sure we really release the button, ignoring micro pulses.

// Holding buttons:
const byte RepeatWhenWeHoldAmount = 15;  // For how long (cycles) to wait when holding the button, before considering is holded
const byte RepeatWhenWeHoldFrequencyDelay = 0;  // How often (cycles) repeat pulses when we hold the button.
                                // 0 = one cycle pulse and one cycle no (101010101...)
                                // 1 = pulse every 2 cycles (1001001001...)
                                // 2 = pulse every 3 cycles (1000100010001...)

const byte WeightYPosition = 50;  // The Y position of the weight when in normal screen
const byte SelectBoxWigth = 55;  // This is how wide the selection box is when is in the center
const byte SelectBoxHeight = 12;  // This is how high the selection box is

const byte SelectBoxXPositionRight = 73;  // X position of the selection box that goes to the right
const byte SelectBoxYPosition = 52;  // Y position of the selection box
const byte SelectBoxXPositionCenter = 36;  // X position of the selection box that goes to the center

const byte ProgressBarSpeedAmount = 5;  // How many cycles to wait to increase the progress bar by 1 pixel.
                                        // The higher, the slower the bar will increase.

// Text Cursor:
const byte BlinkingCursorAmount = 5;  // How many cycles go between blincking the cursor when editing text.
                                      // The higher, the slower is going to do the blinking.





/////////////
// Variables:
/////////////

// Values set in the full calibration process:
long EmptyHolderRawValue;  // The raw value when nothing is in the holder. Set in the full calibration
int EmptySpoolMeasuredWeight;  // The weight when the holder has an empty spool

long FullSpoolRawValue;  // The raw value when a full spool is in the holder. Set in the full calibration
long FullSpoolWeight;  // Weight (g) that a full spool has when calibrating. Set in the full calibration


byte VariableCalibrationDone;  // Stores the readed value of the EEPROM to know if we have done the full calibration before
                               // 0 = Never done before
                               // 1 = Full calibration has been done before

// Deadzone to the weight:
byte DeadzoneSamples = 0;  // Dead zone amount. This will update the shown value only if the reading is below
                           // or greater than the current shown value by a set amount.
                           // 0 means no deadzone.
                           // 1 means the new value have to go over last value by 2 to refresh.
                           // This is set by the user in the menu system.

byte ProgressBarCounter;  // Counter for progress bar
byte ProgressBarSpeedCounter;  // The counter for the speed of the progress bar


byte WeightXPosition;  // X position to display the weight. It depends on the amount of digits so I later change this depending on that

long FullCalibrationRawValueEmptyHolder;  // EEPROM with calibrated zero raw value

byte BlinkingCursorCounter;  // Counter for blincking the cursor when editing text
byte BlinkingCursorState = 1;  // State for blincking the cursor when editing text

long RawLoadCellReading;  // Raw reading from load cell
long HolderWeight;  // Current weight converted to grams, based on calibration
long CurrentProfileWeightShown;  // This variable stores the weight minus the weight of the empty spool on the current profile
long SmoothedWeight;  // Weight with smooth so is more stable
long SmoothedWeightToShowAsInputInDeadzone;  // When we are in deadzone selection, this is the input is going to show

char CurrentProfileTitle[22];  // Character array for current profile name
char ProfileTitleTemporal[22] = "PROFILE 1";  // Character array for profile name before checking the amount of characters.
                                              // The current profile name is stored here, readed from EEPROM
byte AmountOfCharProfileName = 5;  // Stores the temporal amount of characters
                                   // Maximum 21 characters supported

byte DeadzoneAmountSet = 1;  // Amount of deadzone set by the user
long WeightWithDeadzone;  // Weight with deadzone
long FinalWeightToShow;

// Variables for smoothing weight:
long readings1[numReadings1];  // The input
int readIndex1;  // The index of the current reading
long total1;  // The running total

// Variables for debouncing button setting:
byte ButtonDebouncingLastState;  // Stores last state of the button
byte ButtonDebouncingCounter;  // Counter for how long to wait before considering button was really release


// Variables for Enter button:
byte ButtonEnterDebouncingCounter;
byte ButtonEnterDebouncingLastState;
byte EnterButtonActivationStateWithDebounce;
byte EnterButtonHoldRepeatCounter;
byte EnterButtonHoldCounter;
byte EnterButtonActivationStatePulses;
byte EnterButtonActivationStateLongHold;
byte EnterButtonRepeatWhenWeHoldFrequencyCounter;

byte EnterButton1PulseOnly;  // When you press a button, this variable is going
                             // to be value 1 only one cycle. The next cycle is going to be 0.
                             // This is to avoid exceuting the button action continuesly.
                             // I want to do the aciton only one cycle.

byte EnterRepeatWhenWeHoldFrequencyCounter;  // Counter to know how often create repeat pulses when holding the button


// Variables for right button:
byte ButtonRightDebouncingLastState;  // Stores last state of the button
byte ButtonRightDebouncingCounter;  // Counter for how long to wait before considering button was really release

// There are many places where we use the Right button, so instead of repeating the debouncing all the time,
// I read the button and debounce ones and record the state of the button to the following variable.
// If the variable is 1, we excecute whatever we need to do when we press the button.
byte RightButtonActivationStateWithDebounce;  // Stores if we are pressing the button, with debounce

byte RightButtonActivationStatePulses;  // Stores state of (+) button pulses
byte RightButtonActivationStateLongHold;  // Stores if we are long-holding the button. Goes to 1 when we are holding
byte RightButtonRepeatWhenWeHoldFrequencyCounter;  // Counter to know how often create repeat pulses when holding the button
byte RightButtonHoldRepeatCounter;  // Counts for how long we are holding the Right button

// Variable to record if Right button action was already done so we don't excecute commands continuosly:
byte RightButtonHoldCounter;

byte RightButton1PulseOnly;  // Variable to store one pulse only for Right button

// Variables for Left button:
byte ButtonLeftDebouncingLastState;  // Stores last state of the button
byte ButtonLeftDebouncingCounter;  // Counter for how long to wait before considering button was really release

// There are many places where we use the Left button, so instead of repeating the debouncing all the time,
// I read the button and debounce ones and record the state of the button to the following variable.
// If the variable is 1, we excecute whatever we need to do when we press the button.
byte LeftButtonActivationStateWithDebounce;  // Stores if we are pressing the button, with debounce
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
void loop()  // Start of loop
{

  // Read EEPROM:
  EmptyHolderRawValue = readLongFromEEPROM(EEPROM_AddressEmptyHolder);  // Read EEPROM Full Calibration raw value when holder is empty
  FullSpoolRawValue = readLongFromEEPROM(EEPROM_AddressFullSpool);  // Read EEPROM Full Calibration raw value when holder is full
  FullSpoolWeight = readLongFromEEPROM(EEPROM_AddressFullSpoolWeight);  // Read EEPROM Full Calibration raw value when holder is full
  DeadzoneAmountSet = EEPROM.read(EEPROM_AddressDeadzoneAmount);  // Read EEPROM for the amount of deadzone for the shown weight
  CurrentProfileUserSlot = EEPROM.read(EEPROM_AddressCurrentProfileSlot);  // Read EEPROM for the current profile slot number


  // Read EEPROM for the user profile slot order sequence and put it in the variable:
  UserProfileSlotSequence[0] = EEPROM.read(EEPROM_UserProfileSlotOrderSequence[0]);
  UserProfileSlotSequence[1] = EEPROM.read(EEPROM_UserProfileSlotOrderSequence[1]);
  UserProfileSlotSequence[2] = EEPROM.read(EEPROM_UserProfileSlotOrderSequence[2]);
  UserProfileSlotSequence[3] = EEPROM.read(EEPROM_UserProfileSlotOrderSequence[3]);
  UserProfileSlotSequence[4] = EEPROM.read(EEPROM_UserProfileSlotOrderSequence[4]);
  UserProfileSlotSequence[5] = EEPROM.read(EEPROM_UserProfileSlotOrderSequence[5]);
  UserProfileSlotSequence[6] = EEPROM.read(EEPROM_UserProfileSlotOrderSequence[6]);
  UserProfileSlotSequence[7] = EEPROM.read(EEPROM_UserProfileSlotOrderSequence[7]);
  UserProfileSlotSequence[8] = EEPROM.read(EEPROM_UserProfileSlotOrderSequence[8]);
  UserProfileSlotSequence[9] = EEPROM.read(EEPROM_UserProfileSlotOrderSequence[9]);
  UserProfileSlotSequence[10] = EEPROM.read(EEPROM_UserProfileSlotOrderSequence[10]);
  UserProfileSlotSequence[11] = EEPROM.read(EEPROM_UserProfileSlotOrderSequence[11]);
  UserProfileSlotSequence[12] = EEPROM.read(EEPROM_UserProfileSlotOrderSequence[12]);
  UserProfileSlotSequence[13] = EEPROM.read(EEPROM_UserProfileSlotOrderSequence[13]);
  UserProfileSlotSequence[14] = EEPROM.read(EEPROM_UserProfileSlotOrderSequence[14]);
  UserProfileSlotSequence[15] = EEPROM.read(EEPROM_UserProfileSlotOrderSequence[15]);
  UserProfileSlotSequence[16] = EEPROM.read(EEPROM_UserProfileSlotOrderSequence[16]);
  UserProfileSlotSequence[17] = EEPROM.read(EEPROM_UserProfileSlotOrderSequence[17]);
  UserProfileSlotSequence[18] = EEPROM.read(EEPROM_UserProfileSlotOrderSequence[18]);
  UserProfileSlotSequence[19] = EEPROM.read(EEPROM_UserProfileSlotOrderSequence[19]);


  // Match the correct Profile number to the Profile slot:
  CurrentProfileEEPROMSector = UserProfileSlotSequence[CurrentProfileUserSlot];
    
  // Read EEPROM EmptySpoolMeasuredWeight depending on the profile is on:
  EmptySpoolMeasuredWeight = readIntFromEEPROM(EEPROM_AddressEmptySpoolMeasuredWeightProfile[CurrentProfileEEPROMSector]);  // Read EEPROM Profile Tare measured weight when spool is empty

  // Read all EEPROM profile sectors to count how many are in use:
  AmountEEPROMAmountSectorsUsed = 0;  // Reset so we can start counting from scratch
  CounterForWhileEEPROMSectorState = 0;  // Reset counter to start counting from scratch

  while(CounterForWhileEEPROMSectorState < 20)
  {
    if(EEPROM.read(EEPROM_AddressActiveOrDisabledProfile[CounterForWhileEEPROMSectorState]) == 1)  // If the EEPROM sector is already in use (enabled)
    {
      AmountEEPROMAmountSectorsUsed = AmountEEPROMAmountSectorsUsed + 1;  // Increase counter to count how many sectors are available
    }
    CounterForWhileEEPROMSectorState = CounterForWhileEEPROMSectorState + 1;  // Increase counter so we can later check the same for the next sector
  }





  // Read load cell only if it's available. This is so the loop run faster
  if(scale.is_ready())
  {
    RawLoadCellReading = scale.read();
    RawLoadCellReading = RawLoadCellReading /10;  // Remove one digit from the raw reading to reduce the value and could be handle by the map function
  }
  

  // Remap to convert Raw Values into grams:
  HolderWeight = map (RawLoadCellReading, EmptyHolderRawValue, FullSpoolRawValue, 0, FullSpoolWeight);  // Remaps temperature IN to color value
  HolderWeight = constrain(HolderWeight, 0, 9999);  // limits value between min and max to prevent going over limits

  // Add to the measurement the weight of the empty spool in that profile so we measure the weight of the filament only:
  CurrentProfileWeightShown = HolderWeight - EmptySpoolMeasuredWeight;
  CurrentProfileWeightShown = constrain(CurrentProfileWeightShown, 0, 9999);  // limits value between min and max to prevent going over limits



  // Smooth Weight:
  // Smoothing process:
  // Subtract the last reading:
  total1 = total1 - readings1[readIndex1];
  // Read value:
  readings1[readIndex1] = CurrentProfileWeightShown;
  // Add the reading to the total:
  total1 = total1 + readings1[readIndex1];
  // Advance to the next position in the array:
  readIndex1 = readIndex1 + 1;

  // if we're at the end of the array...
  if (readIndex1 >= numReadings1)
  {
    readIndex1 = 0;    // Wrap around to the beginning
  }

  // Calculate the average:
  SmoothedWeight = total1 / numReadings1;

  // End of smoothing process






  /////////////
  // Buttons //
  /////////////

  // ENTER button:

  // Debouncing for ENTER button:
  if (digitalRead(EnterButtonPin) == HIGH)  // If button is release, do the following:
  {
    if (ButtonEnterDebouncingCounter == ButtonDebouncingAmount)  // If wait long enough to see if button was really release
    {
      ButtonEnterDebouncingLastState = 0;  // Record that it was release
      EnterButtonActivationStateWithDebounce = 0;  // Record that the debouncing say that we release the button
    }
    else  // If we didn't wait long enough to see if button was really release:
    {
      ButtonEnterDebouncingCounter++;  // Increase counter to keep waiting if button was really release
    }
  }
  else  // If button is press, do the following:
  {
    ButtonEnterDebouncingCounter = 0;  // Reset debouncing counter
    if (ButtonEnterDebouncingLastState == 0)  // If button was released
    {
      ButtonEnterDebouncingLastState = 1;  // Record that button is press
    }
    if (ButtonEnterDebouncingCounter < ButtonDebouncingAmount)  // If is not yet at the limit...
    {
      ButtonEnterDebouncingCounter++;  // Increase counter to keep waiting
    }
    EnterButtonActivationStateWithDebounce = 1;  // Record that debouncing say that we are still pressing the button
  }
  // End of ENTER button debouncing
  

  // Do ENTER button action:
  if(EnterButtonActivationStateWithDebounce == 1)  // If debouncing state of the button say we are pressing the button:
  {
    // Put whatever you want to do when we press the button:
      
    //FlashingCounter = 0;  // Reset flashing counter to stop the flashing
    //FlashState = 1;  // Set flasher state as ON to prevent from flashing while holding the ENTER button
    //framecount2 = 0;  // Reset counter to prevent from going to normal mode automaticly after some time has passed
    EnterButtonHoldRepeatCounter++;  // Increase counter to know for how long we are pressing the button


    // Do only one pulse for the ENTER button:
    if(EnterButtonHoldCounter < 1)  // If the button was not excecuted already:
    {
      // Put whatever you want to do while button is press:
      EnterButtonActivationStatePulses = 1;  // Write state of the ENTER button as active
      EnterButton1PulseOnly = 1;
    }
    else  // If the button was excecuted already:
    {
      EnterButtonActivationStatePulses = 0;  // Write state of the ENTER button as inactive
      EnterButton1PulseOnly = 0;  // Store that we already go through a pulse, so now we are in off position
    }
    EnterButtonHoldCounter = 1;  // Record that we already excecute the action for one pulse, to prevent from excecuting again


    // Repeat when long-holding button:
    if(EnterButtonHoldRepeatCounter > RepeatWhenWeHoldAmount)  // If we hold the button for long enough:
    {
      EnterButtonHoldRepeatCounter = RepeatWhenWeHoldAmount + 1;  // Prevents the counter from going indefinitely up
      // Put whatever you want to do when we hold the button for long enough:
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

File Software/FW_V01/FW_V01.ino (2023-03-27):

#include <HX711_ADC.h> // https://github.com/olkal/HX711_ADC
#include <PinButton.h> //https://github.com/poelstra/arduino-multi-button/
#include <U8glib.h>  //https://github.com/olikraus/u8glib
#include <math.h>

#define CalibrationFactor 375 // Calibarate your LOAD CELL with 100g weight, and change the value according to readings
#define SpoolMass         250 // Insert mass of your empty filament spool in grams

float j = 0;

PinButton EnterButtonPin(6);  // Pin for ENTER button
PinButton RightButtonPin(5);  // Pin for RIGHT button

//HX711_ADC LoadCell(4, 5); // dt pin, sck pin
HX711_ADC LoadCell(2, 3); // dt pin, sck pin

//U8GLIB_SSD1306_128X32 u8g(U8G_I2C_OPT_NONE);
U8GLIB_SSD1306_128X64 u8g(U8G_I2C_OPT_NONE|U8G_I2C_OPT_DEV_0);  // Dev 0, Fast I2C / TWI

void drawMass(String input) //draws mass readings on OLED
{  
   u8g.setFont(u8g_font_fub17r);   // select font
   u8g.setPrintPos(0, 20);
   u8g.print(input); 
   u8g.println(" g"); 
}

void setup() {
  // flip screen, if required
  // u8g.setRot180();
  
  LoadCell.begin(); // start connection to HX711
  LoadCell.start(2000); // load cells gets 1000ms of time to stabilize
  LoadCell.setCalFactor(CalibrationFactor); // calibration of load cell

  Serial.begin(9600);

}

void loop() {

  EnterButtonPin.update();
  RightButtonPin.update();
  
  LoadCell.update(); // retrieves data from the load cell
  float i = -LoadCell.getData(); // get output value from the load cell, the minus sign may be removed depending on your loadcell placement

  if (RightButtonPin.isClick()) { //subtracts defined spool mass
    Serial.println("/////////////////////////////////////////////////////////////////////////////////////////////////////////////////////////////////////////////////////////////////////////////////////////////");
    j = -SpoolMass;
  } 
  
  Serial.print(round(i+j));
  Serial.println(" g");

  if (i>=5000){ // overload warning
    i=0;
    Serial.print("Over Loaded"); 
    delay(200);
  }
  
  if (EnterButtonPin.isClick()) { // taring information
    Serial.println("Taring");
    j = 0;
    LoadCell.start(2000);
  }

  u8g.firstPage();  
   do {
   drawMass(String(round(i+j)));
   } while( u8g.nextPage() );
   //delay(500);
}

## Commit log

2023-02-23 Addition of 2nd button (backup button)
    [FilamentSpoolScale.kicad_pcb, FilamentSpoolScale.kicad_sch]
2023-02-24 Board design
    [FilamentSpoolScale-B_Cu.gbr, FilamentSpoolScale-B_Mask.gbr, FilamentSpoolScale-B_Paste.gbr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]
2023-02-26 Testing Software and hw changes
    [FilamentSpoolScale.kicad_pcb]
2023-02-26 Preparing for public alfa release (V0.1)
    [3Dprint_FilamentSpoolScaleV01.3mf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]
2023-02-26 PCB schematic rearangement
    [FilamentSpoolScale-B_Cu.gbr, FilamentSpoolScale-B_Mask.gbr, FilamentSpoolScale-B_Paste.gbr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]
2023-02-27 HW V0.2 and Adaptor for Prusa Original 3D printer
    [3Dprint_FilamentSpoolScaleV01.3mf, 3Dprint_FilamentSpoolScaleV02.3mf, PrusaOriginalSpoolAdaptor.3mf]
2023-02-27 individual 3D printed parts
    [body.3mf, cover.3mf, nut.3mf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]
2023-03-05 V02 Hardware and reorganisation
    [0.96 OLED Module - i2C.stp, 3Dprint_FilamentSpoolScaleV01.3mf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]
2023-03-05 PCB PDF edit
2023-03-05 Printable files
    [NormalSpoolHolder.3mf, Nut.3mf, OriginalPrusaAdaptor.3mf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]
2023-03-25 PCB correction
    [FilamentSpoolScale-B_Cu.gbr, FilamentSpoolScale-B_Mask.gbr, FilamentSpoolScale-B_Paste.gbr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]
2023-03-26 V02 hw
    [3Dprint_FilamentSpoolScaleV02.3mf, FilamentSpoolScale.kicad_pcb, FilamentSpoolScale.step]
